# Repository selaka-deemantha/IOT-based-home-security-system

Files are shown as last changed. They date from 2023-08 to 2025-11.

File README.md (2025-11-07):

# IOT-based-home-security-system

This project is an IOT-based home security system that detects intruder entrances using a PIR motion sensor and three magnetic door reed switches. The system consists of two main components: the sensor unit and the WiFi gateway. The sensor unit is a compact device that can be placed in various locations to monitor for intruders. It reads data from the PIR motion sensor and three magnetic door reed switches, and sends the data to the WiFi gateway using ESP-NOW. The WiFi gateway connects to a WiFi network, sends the data to the Blynk cloud using the Blynk library, and displays the data on a Blynk app. It also allows users to control the door locks and alarm using the Blynk app.

<div align="center">
  <table>
    <tr>
      <td align="center" style="padding: 10px;">
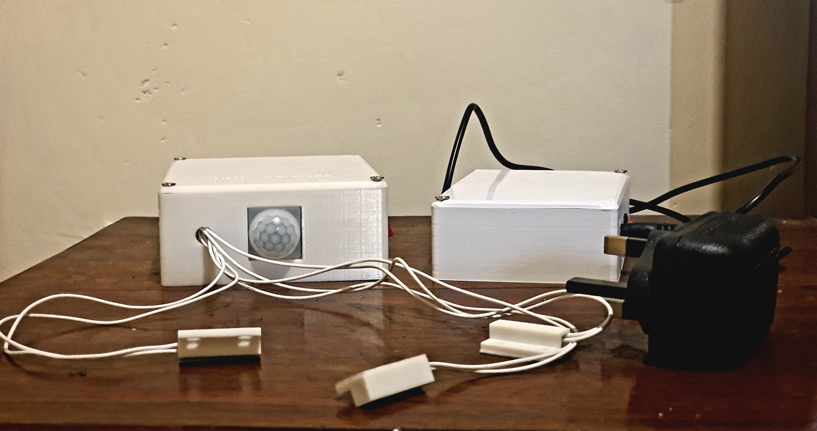
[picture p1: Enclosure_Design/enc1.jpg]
Enc1
        <br>
        <em style="font-size: 0.9em;">Sensor Unit with Hub</em>
      </td>
      <td align="center" style="padding: 10px;">
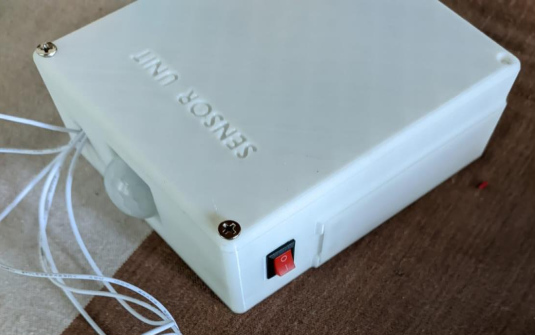
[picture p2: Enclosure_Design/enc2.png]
Exploded View
        <br>
        <em style="font-size: 0.9em;">Sensor Unit</em>
      </td>
    </tr>
  </table>
</div>

## Architecture

The system architecture consists of two main components: the HUB and the Sensor Unit.
<div align="center" style="margin-top: 20px;">
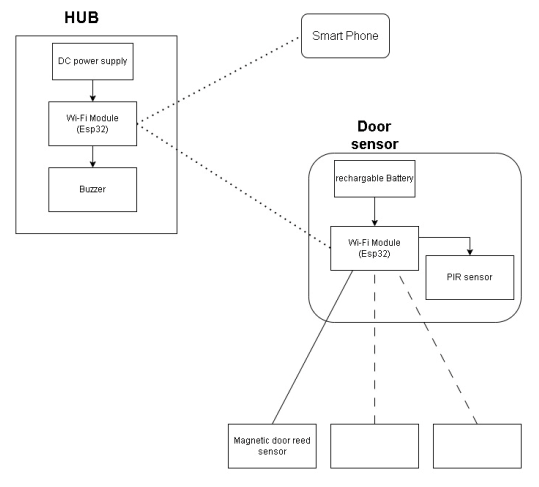
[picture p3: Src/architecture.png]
architecture
    <br>
    <em style="font-size: 0.9em;">Overall Architecture of the design</em>
</div>

### HUB

The HUB is the device that connects to a smartphone and connects one or more sensor units that are attached to doors and windows. It is powered by a 230V power line. The HUB contains three components:

1. DC power supply: To step down 230V to 5V and power the other components in the HUB.
2. 2 Esp32 chips: One chip to communicate with each sensor unit and the other chip to receive the data that the first chip receives from sensor units and upload that data to the smartphone app.
3. Buzzer: To produce an audible alert to notify occupants or authorities of a potential security breach or unauthorized access.

### Sensor Unit

The Sensor Unit is the device that identifies unauthorized entry and communicates with the HUB. The Sensor Unit contains four components:

1. Rechargeable battery: 3.7V 3200mAh rechargeable battery that powers PIR sensor, magnetic door reed, and Wi-Fi module.
2. Magnetic door reed sensor: A magnetic door reed sensor is a device that detects the opening and closing of a door or window using a magnet and a reed switch.
3. PIR sensor: To detect movement inside the house.
4. Esp32 chip: To send the state of the window or door and the output of the PIR sensor to the HUB.

## Project Structure

The project structure consists of the following directories and files:

- `PCB`: Contains the design files for the PCBs used in the project.
- `Enclosure_design`: Contains the design files for the enclosure used in the project.
- `Src`: Contains the source code files for the project.
- `Final_project_Report.pdf`: The project report.
- `README.md`: README file for the project.

## Working Principle

The project consists of two main components: the sensor unit and the WiFi gateway. The sensor unit is responsible for detecting intruders and sending data to the WiFi gateway. It includes the following features:

- Reads data from the PIR motion sensor and three magnetic door reed switches.
- Sends the data to the WiFi gateway using ESP-NOW.
- Enters deep sleep mode when no intruders are detected.

The WiFi gateway receives data from the sensor unit and performs the following actions:

- Connects to a WiFi network.
- Sends the data to the Blynk cloud using the Blynk library.
- Displays the data on a Blynk app.
- Sends commands from the Blynk app to the sensor unit to control the door locks and alarm.

## ESP-NOW Protocol

The sensor unit and WiFi gateway communicate with each other using the ESP-NOW protocol. The ESP-NOW protocol is a lightweight wireless communication protocol that allows for fast and reliable data transfer between ESP8266/ESP32 devices. It is a one-way communication protocol, where the master device sends commands to the slave device. In this project, the WiFi gateway acts as the master device and the sensor unit acts as the slave device. The WiFi gateway sends commands to the sensor unit using ESP-NOW, and the sensor unit responds to the commands by sending data back to the WiFi gateway.

## Dependencies

The project uses the following dependencies:

- Arduino Core for ESP32
- Blynk library
- ESP-NOW library

## Hardware

### Components

- **Microcontroller**: ESP32-WROOM-32
- **Communication Protocol**: ESP NOW
- **Enclosure**: See the `Enclosure_Design/` directory for Solidworks CAD files.
- **Custom PCB**: See the `PCB/` directory for Altium files.
<div align="center">
  <table>
    <tr>
      <td align="center" style="padding: 10px;">
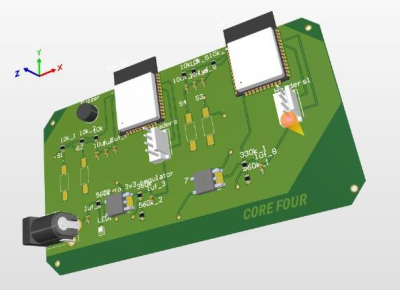
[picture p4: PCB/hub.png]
hub
        <br>
        <em style="font-size: 0.9em;">Hub</em>
      </td>
      <td align="center" style="padding: 10px;">
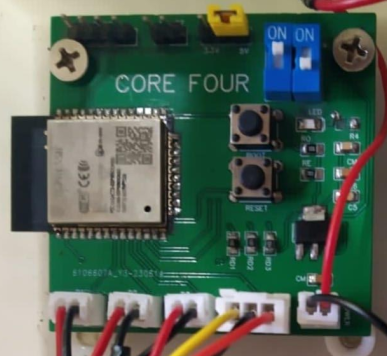
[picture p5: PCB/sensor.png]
sensor unit
        <br>
        <em style="font-size: 0.9em;">Sensor Unit</em>
      </td>
    </tr>
  </table>
</div>

## Future Development

Future improvements for this project include:

- **Migrating to a robust IoT platform** to replace Blynk for better reliability and scalability.
- **Reducing the size of the sensor unit** for a more compact and unobtrusive design.
- **Enhancing the HUB** to support multiple sensor units simultaneously, enabling larger home or office coverage.

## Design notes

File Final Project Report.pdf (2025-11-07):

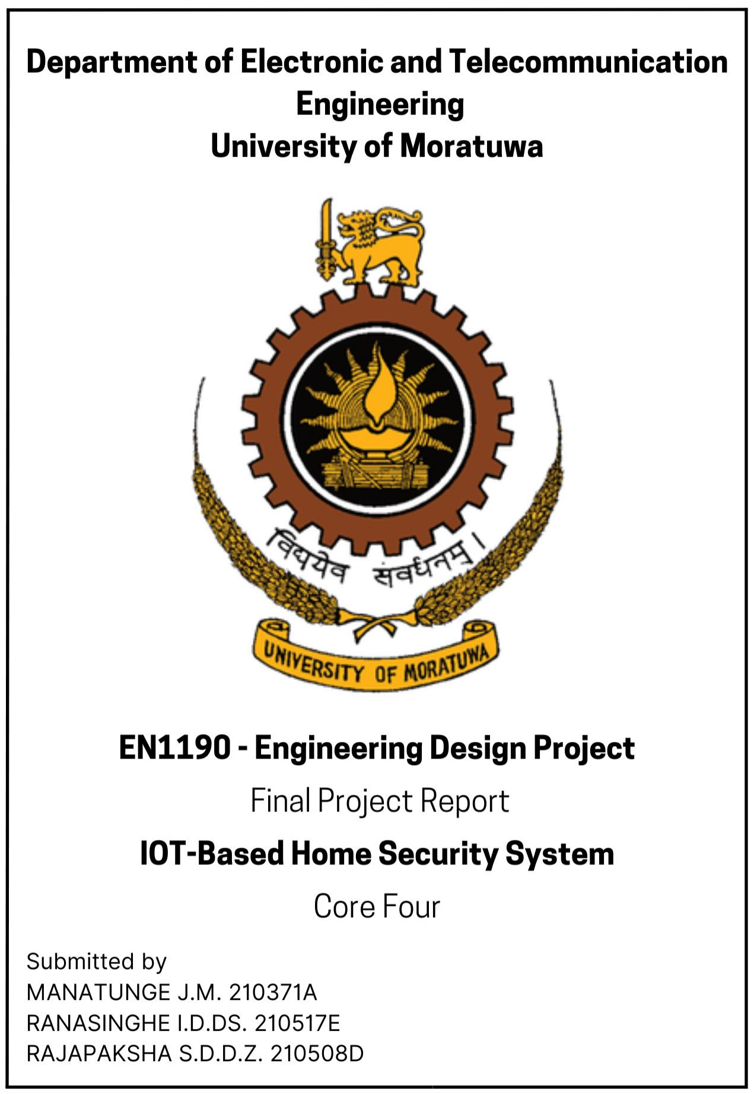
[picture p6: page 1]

## Contents

1. Introduction | 2
1.1. | Problem | 2
1.2. | Is this an actual problem? | 2
1.3. | Justification | 5
2. Technical Feasibility | 5
3. Product Architecture | 6
3.1. | Hub | 6
3.2. | Sensor Unit | 6
3.3. | Smart Phone | 6
4. Initial and Final Sketches of the Enclosure | 7
4.1 Initial Sketch | 7
4.2 Final Sketch | 8
5. Final SolidWorks Designs | 9
5.1 Sensor Unit | 9
5.2 The Hub | 10
6. PCB Designs | 11
6.1 Design for the PCB in the Sensor Unit | 11
6.2 Design for the PCB in the Hub | 12
6.3 Schematic Diagrams | 13
7. Basic Overview of the System | 14
7.1 Power Consumption | 14
8. Further Developments and Improvements | 15
9. Marketing, Sales, and Beyond | 16
10. Project Budget with BOQ | 17
10.1 | Budget for a Sensor Unit | 17
10.2 | Budget for the Hub | 17
10.3 | Manufacturing Process | 17
11. Task Allocation | 18
12. More Information | 18

Overview

Our project is a simple IOT based home security system that alerts users of the open/ closed state of doors & windows and if someone enters their residence. These can be monitored in real-time.

- Done by - Group of engineering undergraduates in Electronics and Telecommunication Department -University of Moratuwa.
1. 210371A – MANATUNGE J.M. (manatungejm.21@uom.lk)
2. 200650U – RANASINGHE I.D.S.S. (ranasingheidss.21@uom.lk)
3. 200683X – RAJAPAKSHA S.D.D.Z. (rajapakshasddz.21@uom.lk)

## 1. Problem Description, Motivation and Justification for selection

### 1.1. Problem

- Because of the economic crisis and the pandemic situation that prevailed in the country, thefts and home invasions are on the rise in Sri Lanka.
- We got this idea after hearing that so many houses were broken into, but due to a security system not being in place the homeowners were not alerted.

### 1.2. Is this an actual concern?

- Home invasions and breaking have always been a problem in Sri Lanka, and the current economic crisis has only worsened it. We have come to understand that this is a serious issue that has made people question the safety of their homes and boarding places.
- From our market analysis, a central hub could cost more than 12,000 LKR while a simple magnetic door reed sensor unit could cost around 5,000 - 8000 LKR. Such units come separately while they don’t have the ability to relay data to an app as it does not come as a system.
- People must put their safety at risk due to the inability to afford such expensive security systems. Furthermore, most systems do not function when there are power cuts.
- As most systems are imported, there is no professional assistance for installation failure.
- Our system integrates many devices used for security purposes together. Both magnetic reed switches and PIR sensors are used while both add an extra layer of protection to one another. The ability to monitor the status of these in real-time while being able to be notified with an alarm is more convenient for the user.
- Such systems in the market are costly. A central hub alone costs more than 10,000 LKR while a sensor unit that only consists of a simple magnetic reed switch costs more than 8,000 LKR while cheaper ones imported from China cost about 6,000 LKR. Most of these sensors do not provide the ability for users to get real-time data.

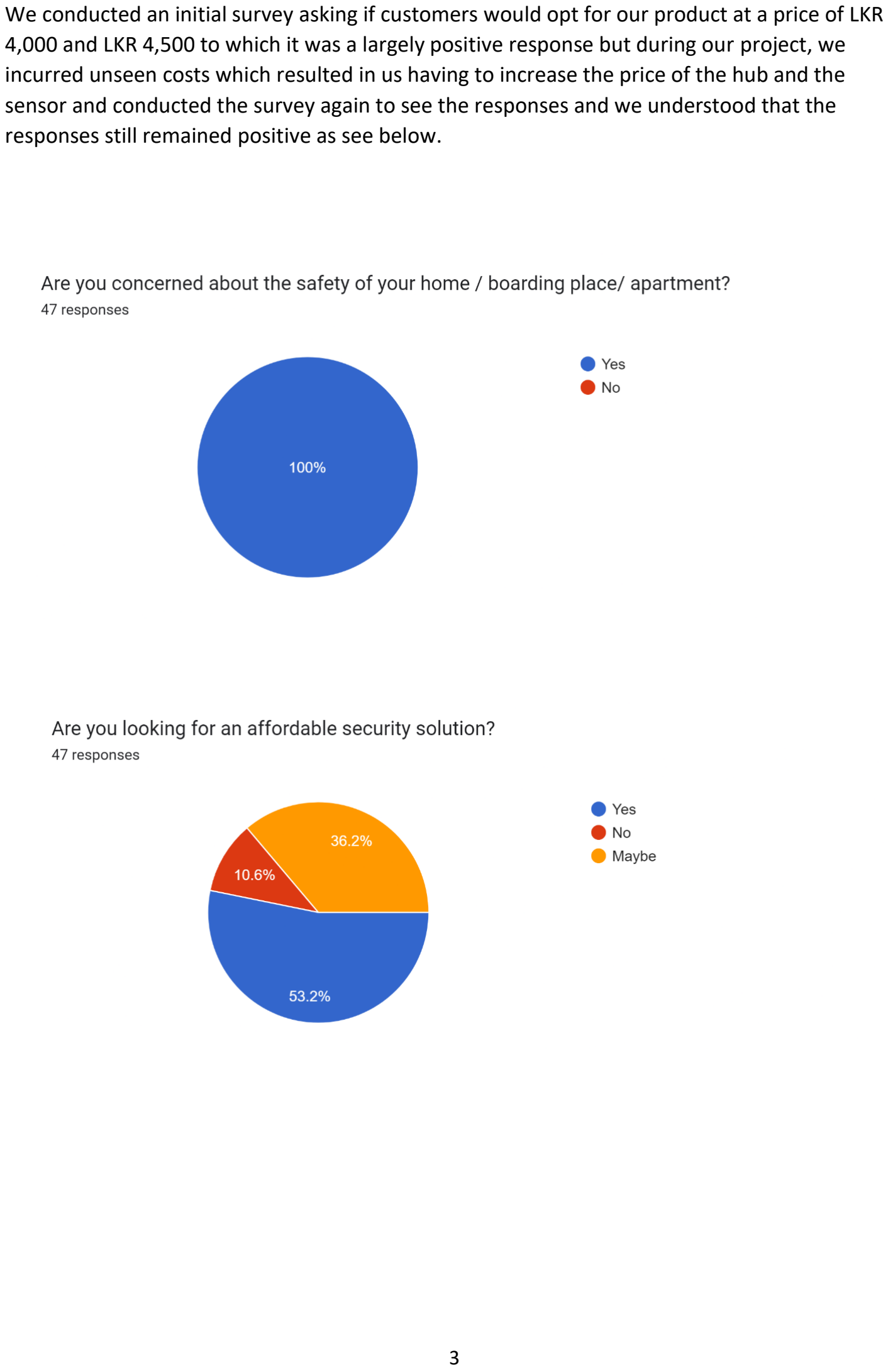
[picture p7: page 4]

We conducted an initial survey asking if customers would opt for our product at a price of LKR 4,000 and LKR 4,500 to which it was a largely positive response but during our project, we incurred unseen costs which resulted in us having to increase the price of the hub and the sensor and conducted the survey again to see the responses and we understood that the responses still remained positive as see below.

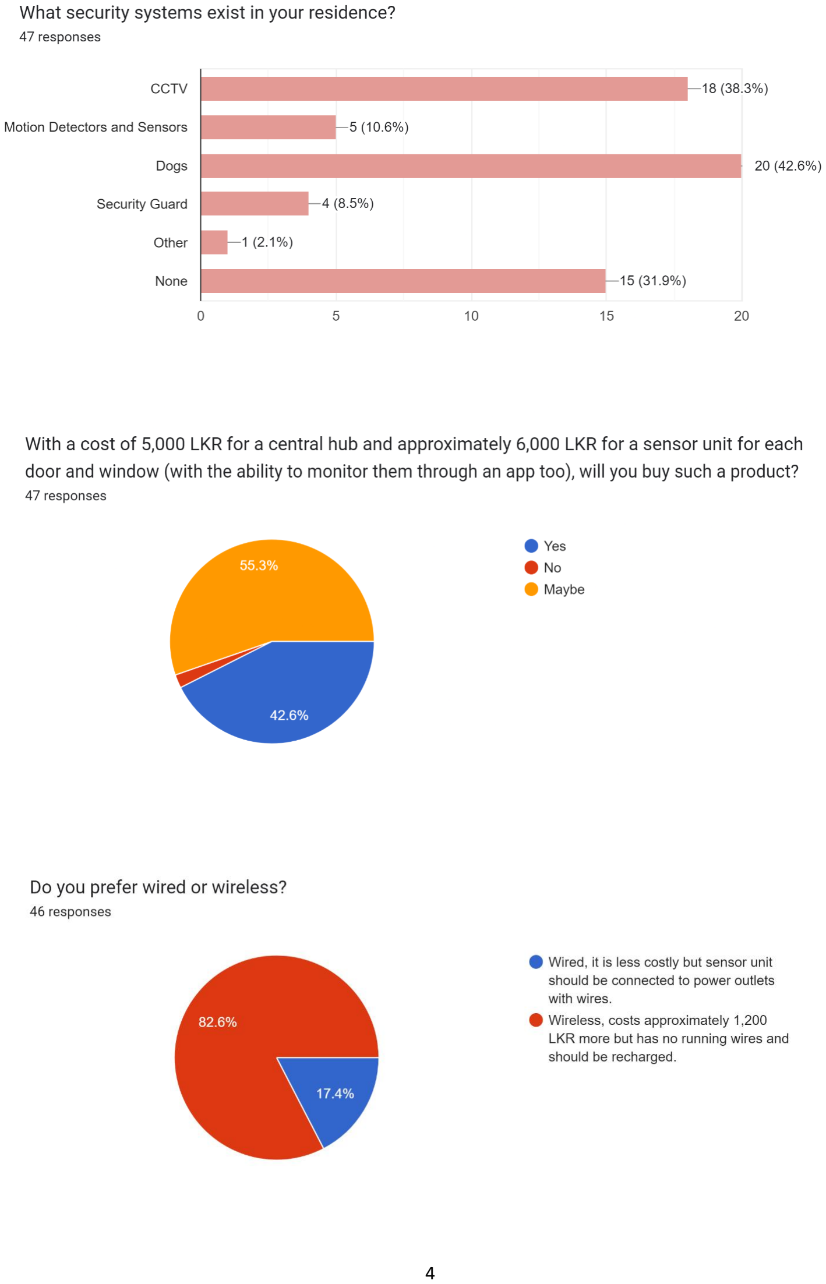
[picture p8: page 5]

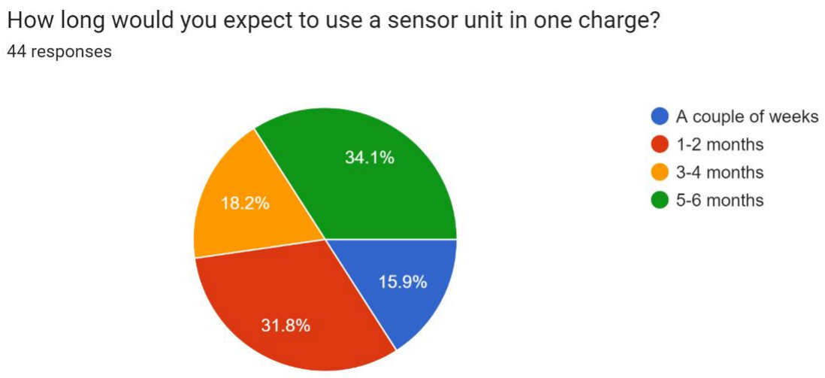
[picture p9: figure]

### 1.3. Justification

These results clearly indicate that people are interested in such a product. We can see through the survey that the most people expect to use the sensor unit wireless and therefore with the use of a rechargeable battery they expect to use the unit for more than 2 months in a single charge but we can manufacture this unit so that it has a life of about 5 months. We can produce a hub with a cost margin of about 2,200 LKR while producing a sensor unit with a cost margin of about 1,700 LKR. As users buy multiple sensor units this would satisfy the market. Most people have spent excess of 100,000 LKR on such security systems.

All the facts and survey results mentioned above indicate that a security system has become an essential piece of equipment in every house and residence. As a result, we can be confident that our product will be very valuable to clients and will be in high demand in the market, and we can plan for future advancements based on that need.

## 2. Technical Feasibility

### 2.1. Performance Targets

- Detect thieves and home invasions.
- Show real-time data of the Open /Closed state of doors and windows.
- Notify the user with an alarm sound.
- Operation of the sensor unit for about.

### 2.2. Availability of Hardware components

Needs of this design project include some Hardware and Software. Hardware that are used and

their corresponding performance targets are mentioned below.

1) To detect motions, we need a sensor which triggers only in the case of motion of a human

being. So, there is a sensor in the market which is called PIR (Passive infrared sensor). Its

operation is based on infrared rays which emit from living beings. This has a range of up to 10

meters, a single detector placed near the entrance is all that is necessary for rooms with only a

single entrance. A magnetic reed switch is used. This switch operated based on magnetic

attraction and is attached to doors to indicate if they are opened or not.

2) Alert the user through the network, we need a device that has the functionality of providing

connection between our device and a specific mobile phone of a user. The ESP32 IC has an

inbuilt Wi-Fi module to communicate with other ESP32 ICs Module which can be easily found in

the market provides that necessity.

3) Making the time we can use a sensor unit long enough to not be inconvenient. Through the

ESP NOW function we can lengthen this to about 5 months for a user to use a sensor unit in a

single charge.

4) Making an alarm sound is very straightforward, there are several methods and components,

but in our device, we continue with a simple small buzzer.

5) We designed our enclosure for the product in a smart shape which provides much

convenience to users.

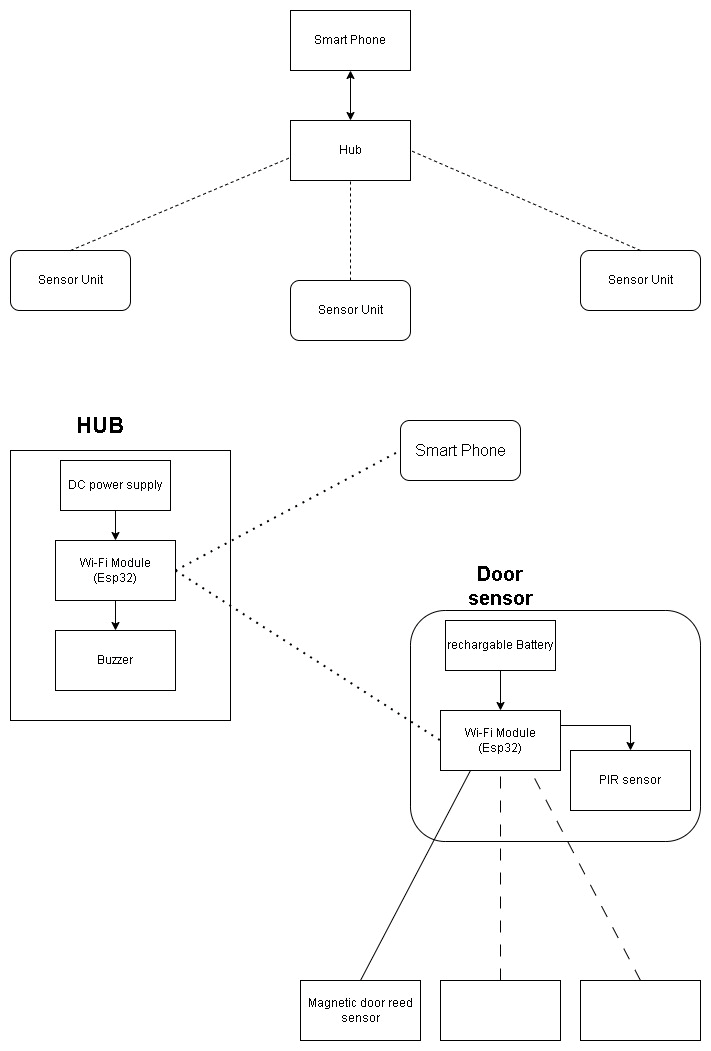
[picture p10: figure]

### 3.1.1 HUB

The hub is the device that connects to a smartphone and connects one or more sensor units that are attached to doors and windows. It is powered by a 230V power line. The hub contains three components.

1. DC power supply- To step down 230V to 5V and power the other components in hub.
2. 2 Esp32 chips -One chip to communicate with each sensor unit and the other chip to receive the data that the first chip receives from sensor units and upload that data to the smartphone app.
3. Buzzer- To produce an audible alert to notify occupants or authorities of a potential security breach or unauthorized access.

### 3.2. SENSOR UNIT

This sensor unit is the device that identifies unauthorized entry and it communicates with the hub. sensor unit contains four components.

1. Rechargeable battery- 3.7V 3200mAh rechargeable battery that powers PIR sensor, magnetic door reed and Wi-Fi module
2. Magnetic door reed sensor- A magnetic door reed sensor is a device that detects the opening and closing of a door or window using a magnet and a reed switch.
3. PIR sensor- To detect movement inside the house.
4. Esp32 chip- To send state of window or door and output of PIR sensor to the hub.

## 3. Product Architecture

### 3.3. SMART PHONE

The app that is installed into the smart phone allows the user to monitor real time data such as the open / close state of door and windows and alerting users when an intrusion occurs. Furthermore, it allows the user to turn on and off the security system. We tested this by using the Blynk app. This app has a cloud to which the one of the Esp32 chips upload data that is then seen in the application.

In our initial product architecture design, we only used one Esp32 chip in the Hub. This was to be used to receive Sensor unit data and simultaneously send it to the mobile app through the internet. I was doable using one Esp32 chip but there were some drawbacks such as the chip taking more time to send data and consuming a lot of power. Furthermore, the ESP-Now and Wi-Fi channels need to share the same channel. Since the Wi-Fi channel changes the Esp32 chip in the sensor unit should scan before sending data to make sure of the channel. This consumes a lot of power from the battery that this Esp32 is powered from and the battery power is a constraint in our project so we needed optimizing the battery usage.

Using two Esp32 chips in the Hub, one chip to communicate with each sensor unit and the other chip to receive the data that the first chip receives from sensor units and upload that data to the smartphone app we can solve the issue of communication.

## 4. Initial and Final Sketches of the Enclosure

### 4.1. Initial Sketch

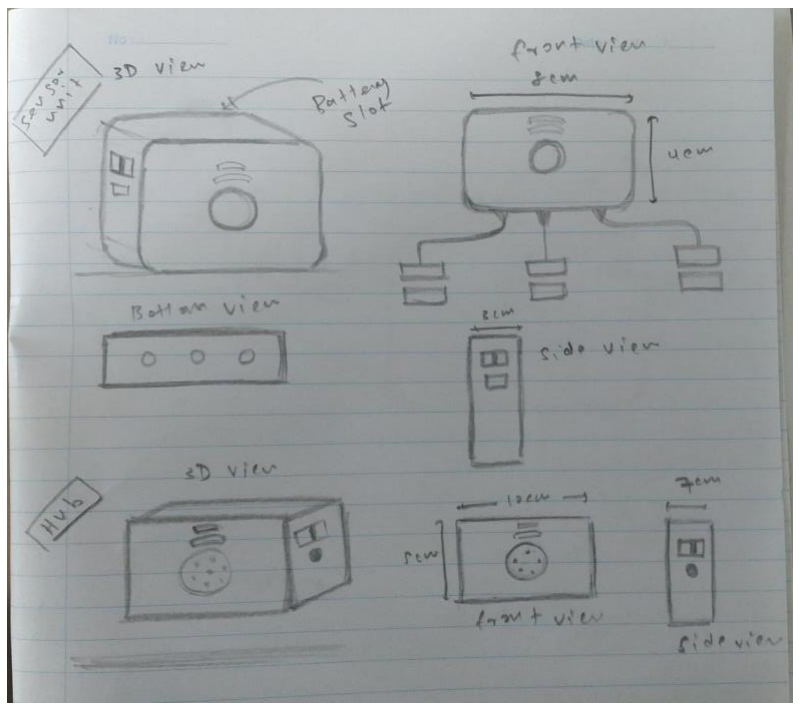
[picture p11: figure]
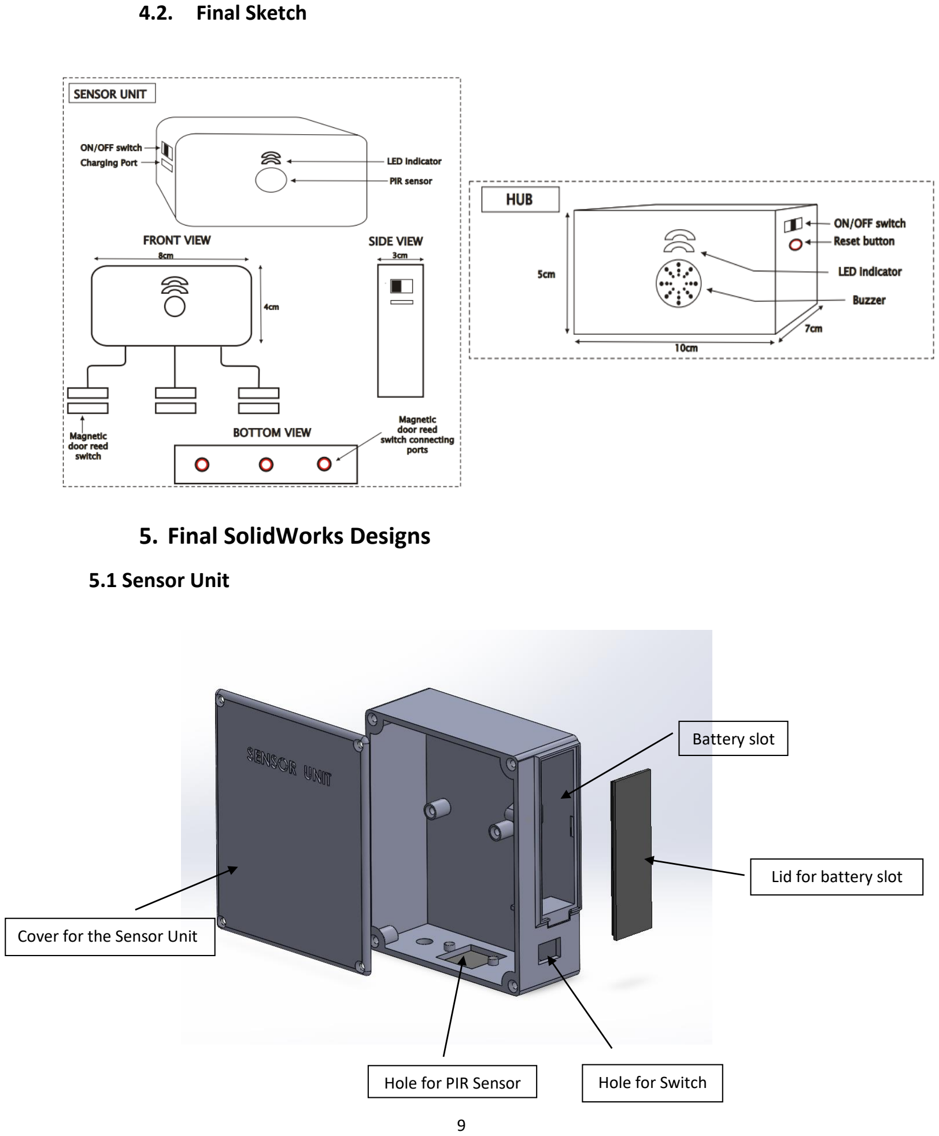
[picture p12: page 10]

### 4.2. Final Sketch

## 5. Final SolidWorks Designs

### 5.1 Sensor Unit

Cover for the Sensor Unit

Hole for PIR Sensor | Hole for Switch

Lid for battery slot

Battery slot

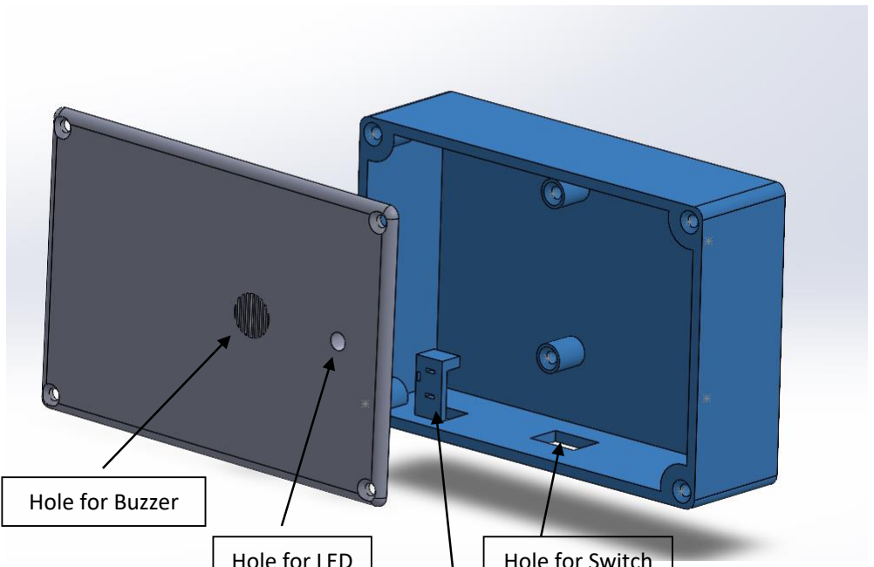
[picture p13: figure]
Hole for Buzzer

Hole for LED | Hole for Switch

Dimensions of Sensor Unit

Height = 12.1 cm Width = 10.1 cm Thickness = 4.1 cm Total volume = 501.05 cm³
Weight - 150g

### 5.2 The Hub

Dimensions of Hub

Height = 11.9 cm Width = 8.25 cm Thickness = 3.3 cm Total volume = 323.98 cm³
Weight - 150g

Platform to hold the DC base barrel

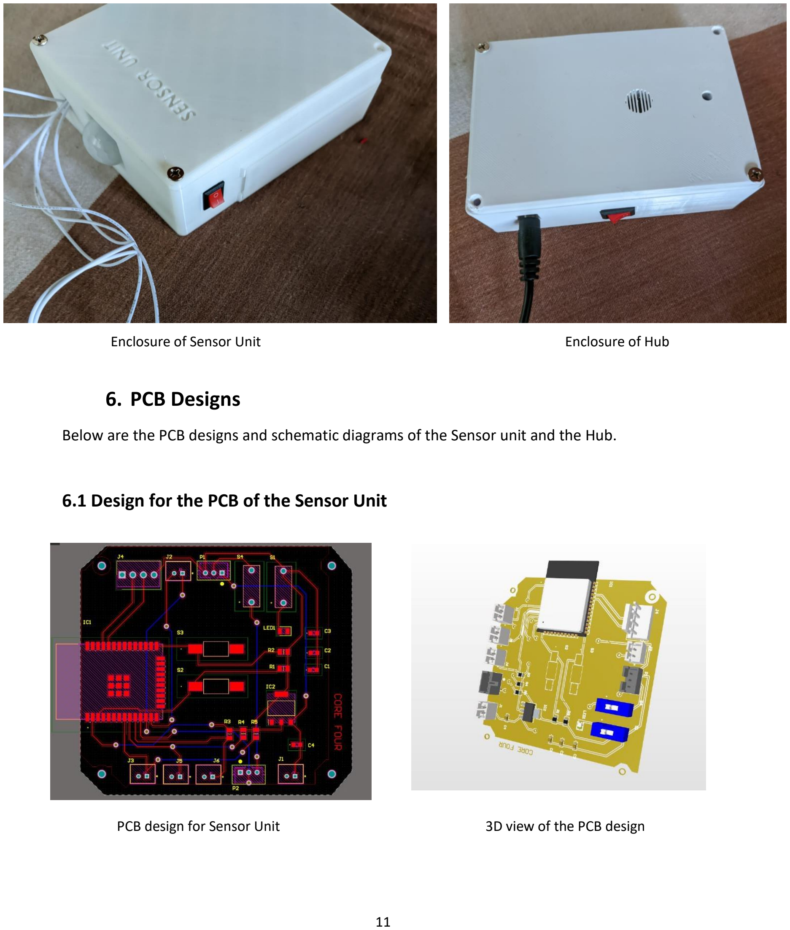
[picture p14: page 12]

PCB design for Sensor Unit | 3D view of the PCB design
Enclosure of Sensor Unit | Enclosure of Hub

## 6. PCB Designs

Below are the PCB designs and schematic diagrams of the Sensor unit and the Hub.

### 6.1 Design for the PCB of the Sensor Unit

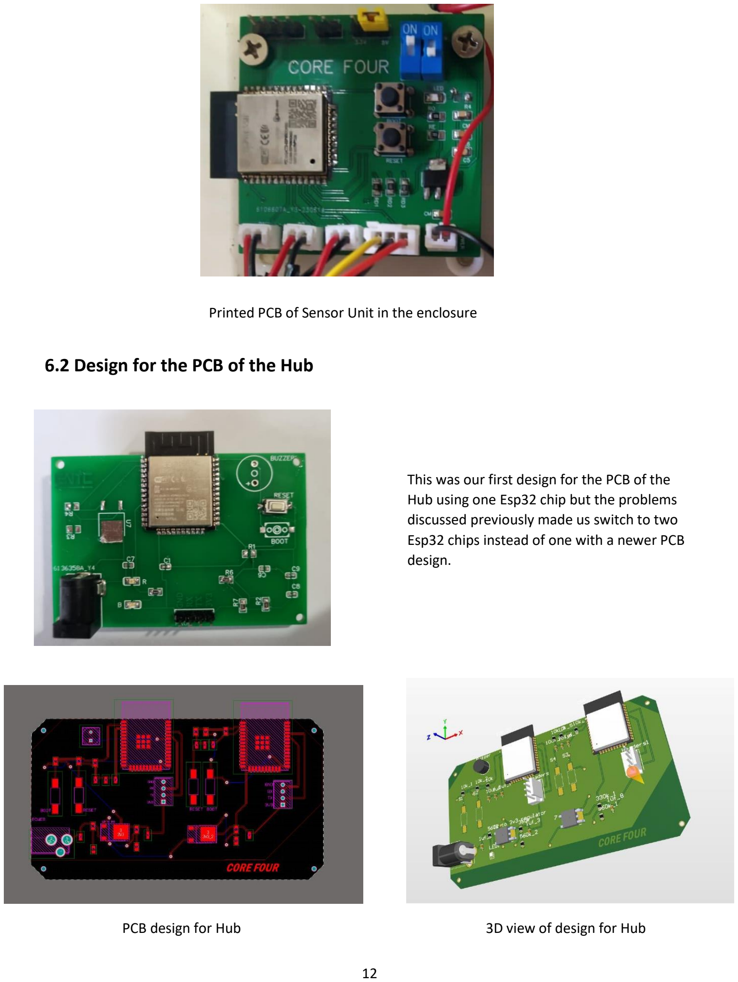
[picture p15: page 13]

PCB design for Hub | 3D view of design for Hub

### 6.2 Design for the PCB of the Hub

Printed PCB of Sensor Unit in the enclosure

This was our first design for the PCB of the Hub using one Esp32 chip but the problems discussed previously made us switch to two Esp32 chips instead of one with a newer PCB design.

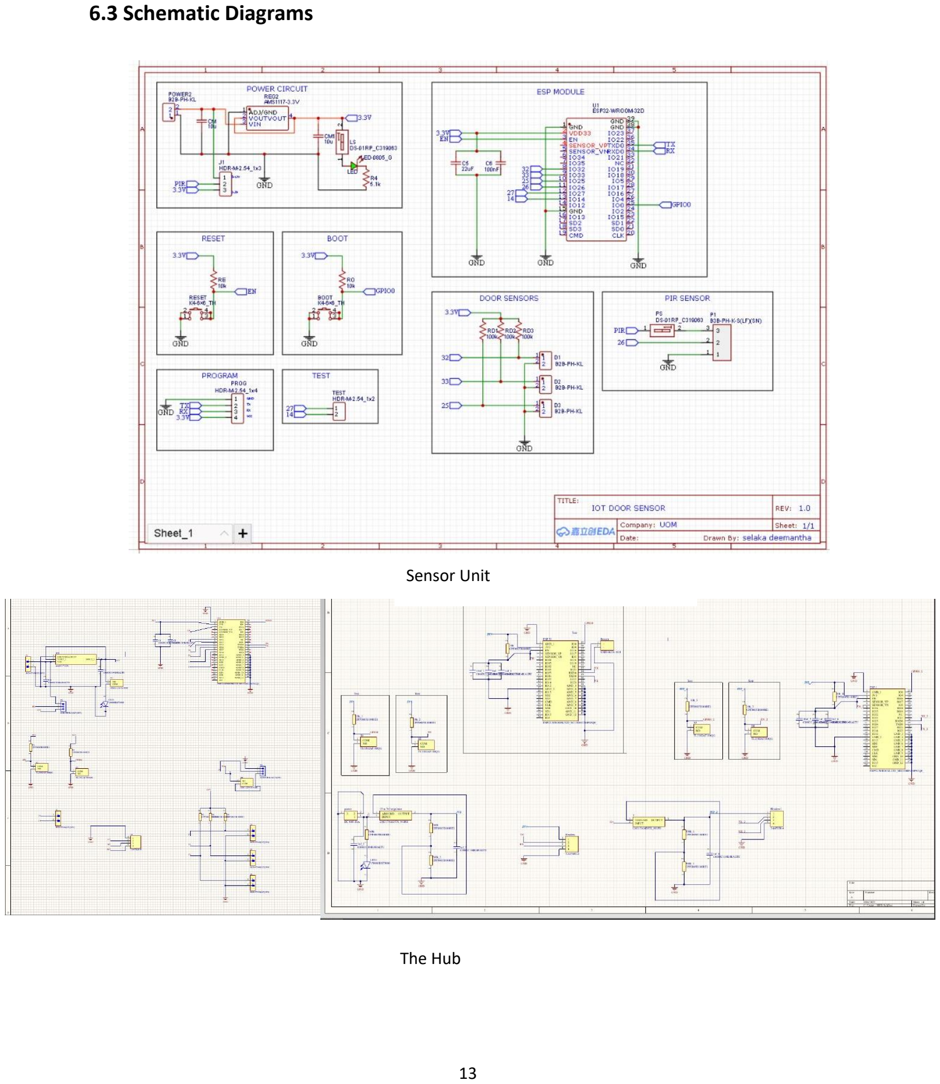
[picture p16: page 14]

### 6.3 Schematic Diagrams

Sensor Unit

The Hub

## 7. A Basic Overview of the System

As mentioned previously the system has three main components: the Sensor Units for data collection, the Hub, and the mobile application.

The system has two modes: safe mode and buzzer mode. Our intentions were to make it able for the user to monitor the opened/ closed state of the doors or windows that the sensor units are mounted to when the safe mode is turned on through the app. We put a switch to the PIR sensor which can be turned on/ off manually. This allows the user to decide when they need to detect motion. The Hub too has a switch which enables the user to turn the buzzer on. An LED is used to indicate if the buzzer is on or off.

When the PIR and Hub switches are on and the safe mode is already turned on, turning the buzzer mode on allows the buzzer to turn on when a motion is detected or a door or window is opened and alerts the user. When the buzzer mode is turned on and one of the above or both occurs the user gets a notification alerting the occurrence and an alarm will ring on the user’s phone.

### 7.1 Power Consumption

Our main concern was the battery life of the sensor unit for a single charge since the Esp32 chip should be powered by it. To overcome this, we made use of the Esp32 chip’s Deep Sleep mode where it only wakes up when a door or window is opened or closed and is awake till the is close or opened or when a motion is detected from the PIR sensor. Simply put, the Esp32 chip in the wakes up to replay the information of a changed state in door or window of the sensor unit. We made the sensor unit in such a way that it can monitor up to a total of 3 doors/ windows since it has three magnetic reed switches.

- While active the Esp32 chip draws a current of 50mA and while in deep sleep mode it draws 100µA.
- If the doors/windows connected to one sensor unit are opened for a total of 2 hours collectively, daily then a user can use a sensor unit for 32 days with this 3200mAh battery.

## 8. Further Developments and Improvements

- Optimizing the power consumption of the battery during the brief wake-up time to extend the charge of a single battery charge.

Currently a sensor unit can only be used for approximately a month from a single charge. But we can improve our code in such a way that the Esp32 chip is woken up when a magnetic reed switch or a PIR sensor is triggered and goes back to sleep right after it relays the message to the Esp32 chip in the Hub. We can limit this brief wake up to about 10s. Therefore, once a trigger happens the Esp32 is only active for 10s before going to sleep again.

This way, if the reed switches and the PIR sensor are triggered a total of 50 times a day, then the Sensor unit will have a power consumption per day will be,

Power consumption per trigger = 50mA*10/ (60*60) = 0.1389mAh

Power consumption per day (50 triggers in total) = 50*0.1389mAh = 6.944mAh

Since we use a 3200mAh battery,

Lifetime of a single charge = 3200mAh / 6.944mAh = 461 days = 1.2 years

If we consider the fact that the charge of rechargeable batteries reduces with time, we can expect a battery life of about 8 months to one year.

- Addition of a battery level indicator in the sensor unit.
- Smaller and better-looking designs for the Sensor unit and the Hub.
- Creation of an application using MQTT protocol for optimized user experience and real-time updates.

## 9. Marketing, Sales & Beyond

People are concerned about security these days because the number of robberies is on the rise. As a result, electronic security systems are in high demand. When it comes to recommending the best product packaging for an IoT-based security system, several factors should be considered, including the product's features, target market, brand identity, and overall customer experience.

There are numerous types of security equipment on the market, such as CCTV and burglar alarms. We have now discovered the substitutes and compared them to our product as the first stage. Higher electricity usage and hefty price tag are such goods' key drawbacks. We chose our tagline for our marketing campaign based on that.
“Secure your home, save energy and money.”

Initially, we will market these products regionally. We will improve our product by introducing additional features once we have captured the local market. We will also enter global markets because of this. Our marketing strategy is consistent with the four Ps of the marketing mix. The pricing of the product is an extremely crucial part of its market success. According to Google, the typical cost of installing a CCTV camera is between USD 150 - USD 450. We intended to sell at a modest markup to catch the early market. Initially, we will offer our product through various e-commerce platforms and tiny local businesses. Once we get public recognition, we will launch our own website to eliminate excessive commission charges. Furthermore, economies of scale can reduce our indirect costs such as shipping. We will begin marketing our product in international nations via ecommerce websites once we have revised our product based on feedback from local users.

Marketing Strategies: The marketing strategies for promoting the IoT-based security system will focus on maximizing reach, targeting the right audience, and showcasing the system's unique features and benefits. The following strategies will be employed:

1. Content Marketing
2. Search Engine Optimization (SEO)
3. Social Media Marketing
4. Pay-Per-Click (PPC) Advertising
5. Strategic Partnerships

Demonstrations and events by implementing these marketing strategies, the IoT-based security system will gain maximum visibility, effectively target the right audience, and showcase its unique features and benefits to drive customer adoption and sales.

Some after sales we can provide are free repairs and the maintenance of the app.

## 10. Project Budget with BOQ

### 10.1. Budget for a Sensor Unit

### 10.2. Budget for the Hub

### 10.3. Manufacturing Process

- PCB printing- Rs 3,500 + Rs 4,200 = Rs 7,700
- Enclosure 3D printing - Rs 2,075 + Rs 2,075 = Rs 4,150
- Soldering wires – Rs 100

Total Budget = 1 x Central Hub + 2 x Sensor Units + Manufacturing Cost
Total Budget = Rs 18,900/=
component | Number of components | Unit price (Rs) | Total prize (Rs)
ESP32 chip | 2 | 1100 | 2200
DC power connector (5v) | 1 | 780 | 780
Buzzer | 1 | 60 | 60
Other (Resistors, capacitors, LEDs, switches, DC base barrel) | | | 620
Total | | | 3,660
component | Number of components | Unit price (Rs) | Total prize (Rs)
ESP32 chip | 1 | 1100 | 1100
Magnetic Reed Switch | 3 | 180 | 540
Rechargeable battery | 1 | 700 | 700
PIR sensor | 1 | 350 | 350
Other (Resistors, capacitors, switches, battery casing) | | | 500
Total | | | 3,290

## 11. Task Allocation

- Javin – Overseeing the project budget and deadlines, market research and marketing, product

architecture and enclosure design using solid works.

- Shenal – PCB designing using Altium Designer and researching and analyzing the technical

feasibility of the project.

- Selaka – Product testing, Circuit designing and Coding.

## . 12. More Information

All our files such as the Altium files, SolidWorks files and video demonstrations have been uploaded to the following GitHub repository.

https://github.com/javin-5/IOT-based_home_security_system.git

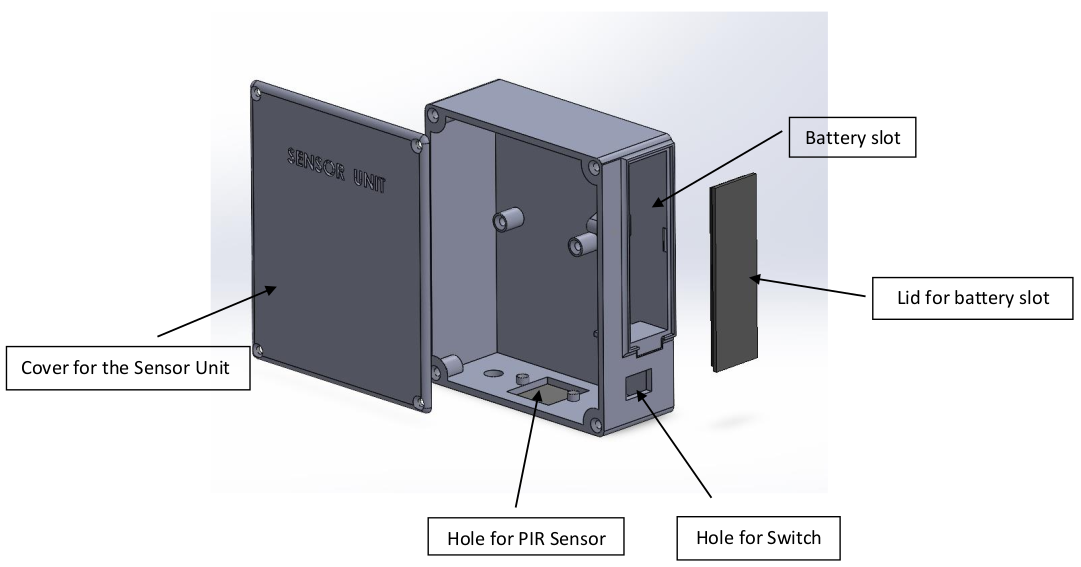
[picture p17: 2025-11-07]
Enclosure_Design/enc_cad.png

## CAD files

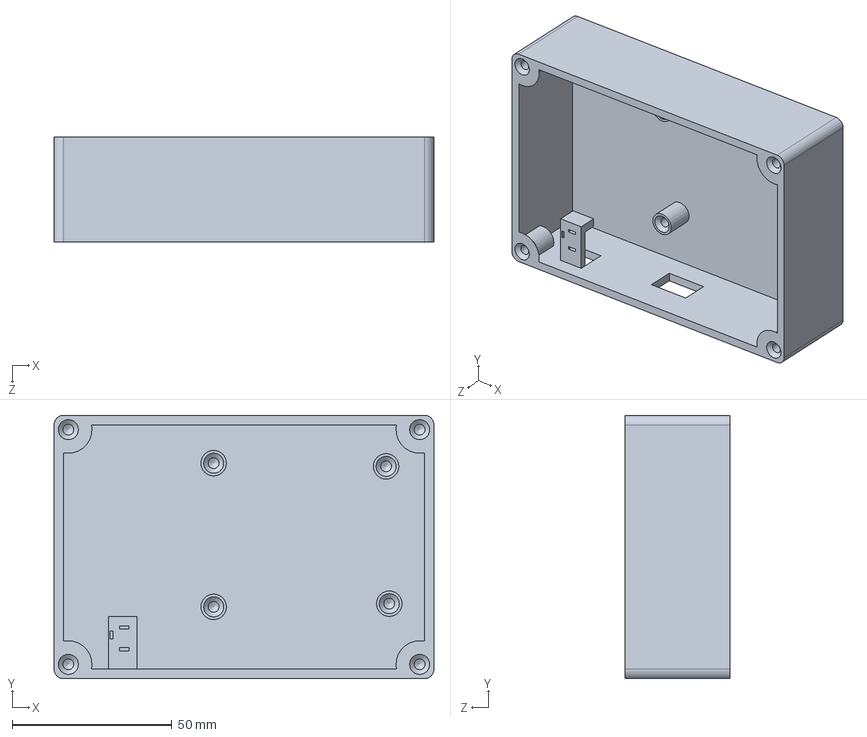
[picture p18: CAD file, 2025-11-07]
Enclosure_Design/hub_case.SLDPRT
119.0 x 82.5 x 33.0 mm

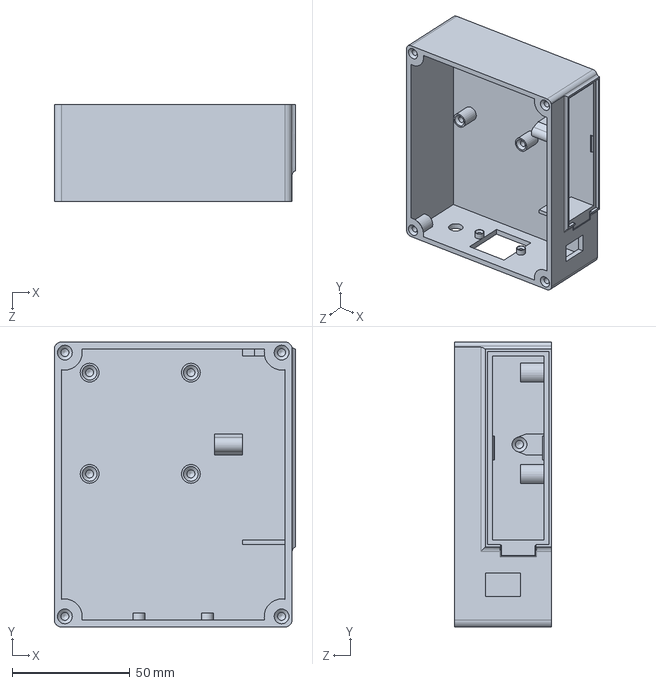
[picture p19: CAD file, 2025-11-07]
Enclosure_Design/sensor_case.SLDPRT
102.5 x 121.0 x 41.0 mm

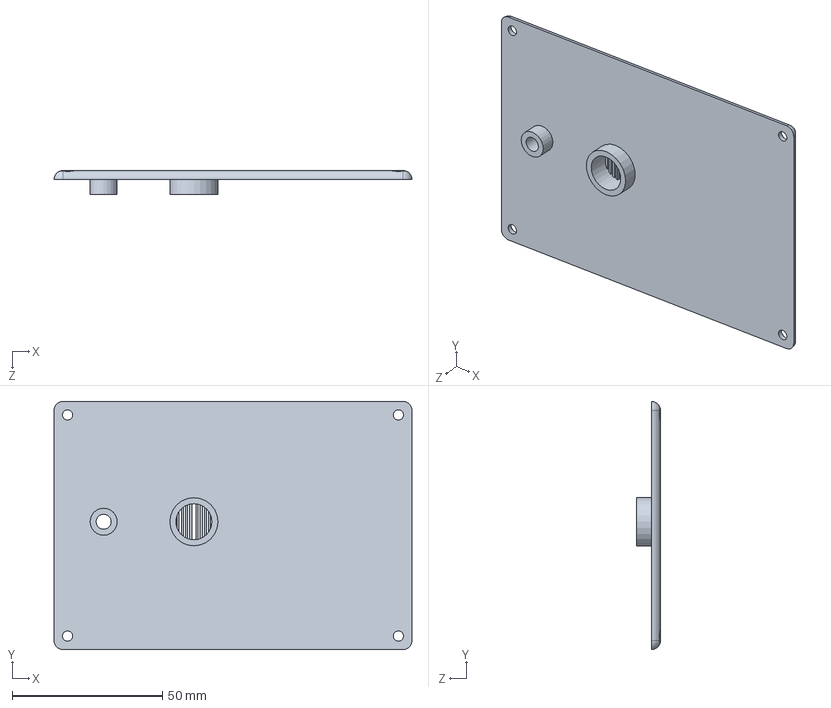
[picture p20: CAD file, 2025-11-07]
Enclosure_Design/hub_cover.SLDPRT
119.0 x 82.5 x 8.00 mm

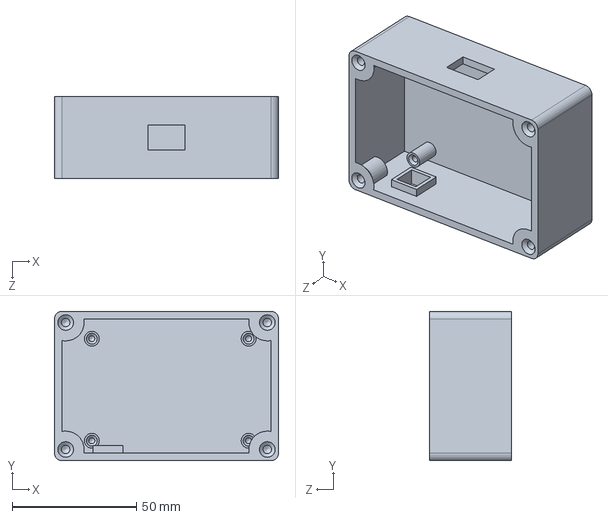
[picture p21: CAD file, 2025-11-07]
Enclosure_Design/case_for_hub_with_new_pcb.SLDPRT
90.0 x 60.0 x 33.0 mm

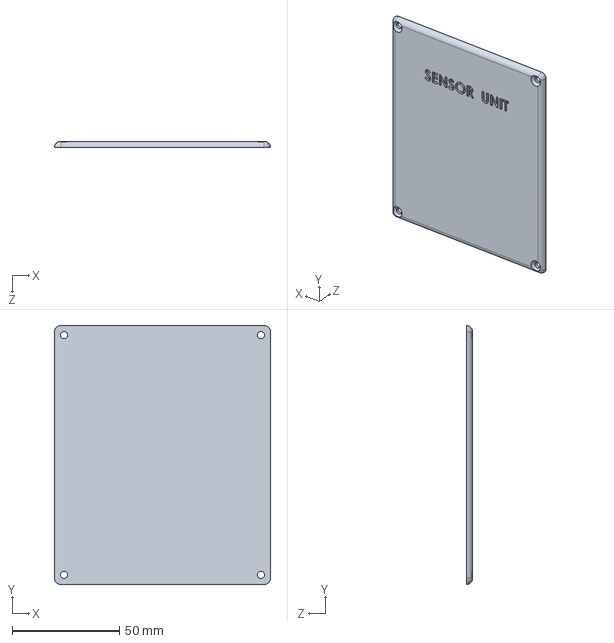
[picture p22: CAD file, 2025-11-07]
Enclosure_Design/sensor_cover.SLDPRT
101.0 x 121.0 x 3.00 mm

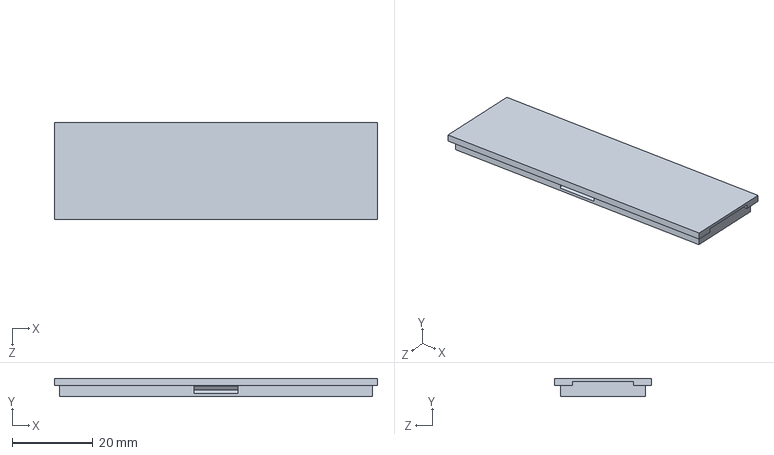
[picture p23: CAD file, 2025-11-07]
Enclosure_Design/lid_for_battery_slot.SLDPRT
80.0 x 4.50 x 24.0 mm

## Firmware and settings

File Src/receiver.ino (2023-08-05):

#define BUTTON_PIN_BITMASK 0x306000000 //bitmask for pin 33,32,25,26

// Include Libraries
#include <esp_now.h>
#include <WiFi.h>
 
// Variables for test data
int door1=32;
int door2=33;
int door3=25;
int pir=26;

 
uint8_t broadcastAddress[] = {0xE0, 0x5A, 0x1B, 0x60, 0x44, 0xD4};
 
// Define a data structure
typedef struct struct_message {
  int DOOR1_STATE;
  int DOOR2_STATE;
  int DOOR3_STATE;
  int PIR_STATE;
  int SENSOR_ID;
} door_state;
 
// Create a structured object
door_state Data;
 
// Peer info
esp_now_peer_info_t peerInfo;
 
// Callback function called when data is sent
void OnDataSent(const uint8_t *mac_addr, esp_now_send_status_t status) {
 
}

void print_wakeup_reason(){
  esp_sleep_wakeup_cause_t wakeup_reason;

  wakeup_reason = esp_sleep_get_wakeup_cause();

  switch(wakeup_reason)
  {
    case ESP_SLEEP_WAKEUP_EXT0 : Serial.println("hhh"); break;
    case ESP_SLEEP_WAKEUP_EXT1 : send_sensor_data(); break;
    case ESP_SLEEP_WAKEUP_TIMER : Serial.println("Wakeup caused by timer"); break;
    case ESP_SLEEP_WAKEUP_TOUCHPAD : Serial.println("Wakeup caused by touchpad"); break;
    case ESP_SLEEP_WAKEUP_ULP : Serial.println("Wakeup caused by ULP program"); break;
    default : Serial.printf("Wakeup was not caused by deep sleep: %d\n",wakeup_reason); break;
  }
}


void setup(){
  Serial.begin(115200);
  pinMode(door1,INPUT);
  pinMode(door2,INPUT);
  pinMode(door3,INPUT);
  pinMode(pir,INPUT);
  WiFi.mode(WIFI_STA);

 if (esp_now_init() != ESP_OK) {
    return;
  }
 
  esp_now_register_send_cb(OnDataSent);
  
  memcpy(peerInfo.peer_addr, broadcastAddress, 6);
  peerInfo.channel = 0;  
  peerInfo.encrypt = false;
  
  if (esp_now_add_peer(&peerInfo) != ESP_OK){
    return;
  }
  
  print_wakeup_reason();
  esp_sleep_enable_ext1_wakeup(BUTTON_PIN_BITMASK,ESP_EXT1_WAKEUP_ANY_HIGH);

  esp_deep_sleep_start();
}

void loop(){
}
void send_sensor_data(){
  while(digitalRead(door1)==1 || digitalRead(door2)==1 || digitalRead(door3)==1 || digitalRead(pir)==1){
  Data.DOOR1_STATE = digitalRead(door1);
  Data.DOOR2_STATE = digitalRead(door2);
  Data.DOOR3_STATE = digitalRead(door3);
  Data.PIR_STATE   = digitalRead(pir);
  Data.SENSOR_ID = 0;
  Serial.println("data sending");
  
  esp_err_t result = esp_now_send(broadcastAddress, (uint8_t *) &Data, sizeof(Data));
  delay(500);
  }
  Data.DOOR1_STATE = 0;
  Data.DOOR2_STATE = 0;
  Data.DOOR3_STATE = 0;
  Data.PIR_STATE   = 0;
  Data.SENSOR_ID = 0;
  esp_err_t result = esp_now_send(broadcastAddress, (uint8_t *) &Data, sizeof(Data)); 
  Serial.println("going to sleep");
}

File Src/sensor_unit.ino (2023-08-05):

// Include Libraries
#include <esp_now.h>
#include <WiFi.h>
#include <WiFiClient.h>

char serData[7]={'0','0','0','0','0'};

typedef struct struct_message {
  int DOOR1_STATE;
  int DOOR2_STATE;
  int DOOR3_STATE;
  int PIR_STATE;
  int SENSOR_ID;
} door_state;
 
door_state myData;
 
// Callback function executed when data is received
void OnDataRecv(const uint8_t * mac, const uint8_t *incomingData, int len) {
  memcpy(&myData, incomingData, sizeof(myData));
  serData[0]=myData.SENSOR_ID+'0';
  serData[1]=myData.DOOR1_STATE+'0';
  serData[2]=myData.DOOR2_STATE+'0';
  serData[3]=myData.DOOR3_STATE+'0';
  serData[4]=myData.PIR_STATE+'0';
}
 
void setup() {
  // Set up Serial Monitor
  Serial.begin(115200);
  
  // Set ESP32 as a Wi-Fi Station
  WiFi.mode(WIFI_STA);
 
  // Initilize ESP-NOW
  if (esp_now_init() != ESP_OK) {
    return;
  }
  
  // Register callback function
  esp_now_register_recv_cb(OnDataRecv);
  
}
 
void loop() {
 Serial.write(serData,6);
 //Serial.println(serData);
 delay(500);
}

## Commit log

2023-08-05 Create PCB
2025-11-07 updated the folder structure
    [HUB.PcbDoc, HUB.SchDoc, Sensorunit.PcbDoc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]
